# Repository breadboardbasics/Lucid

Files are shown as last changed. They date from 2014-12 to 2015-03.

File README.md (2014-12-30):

This is a repository for my Hackaday project here: http://hackaday.io/project/3715-tacs-lucid-dreaming-device

Thanks for checking out my project!
To make everything easier just click the download zip button on the right side of the main page of this repository. 
Then extract everthing to a folder. Next you should be able to view the board and schematic files with KiCad or
you can just view the schematic with the pdf that I included. 

All code that is used in this project will also be posted in this repository and will be updated as I progress through the 
project. 

Also for those wondering RevA (Revision A) is what I am calling the first version of the hardware. It is still a work in 
progress but is almost complete and ready for testing. 

**Disclaimer** - I am not responsible for any damages or injury related to this project
The project is very safe. It is battery powered and has a maximum of about 18v present on the board. Do not attempt to use 
the headset when it is connected to mains (the wall) in any way ex. you are powereing it with the programmer which is connected 
a desktop computer ect.

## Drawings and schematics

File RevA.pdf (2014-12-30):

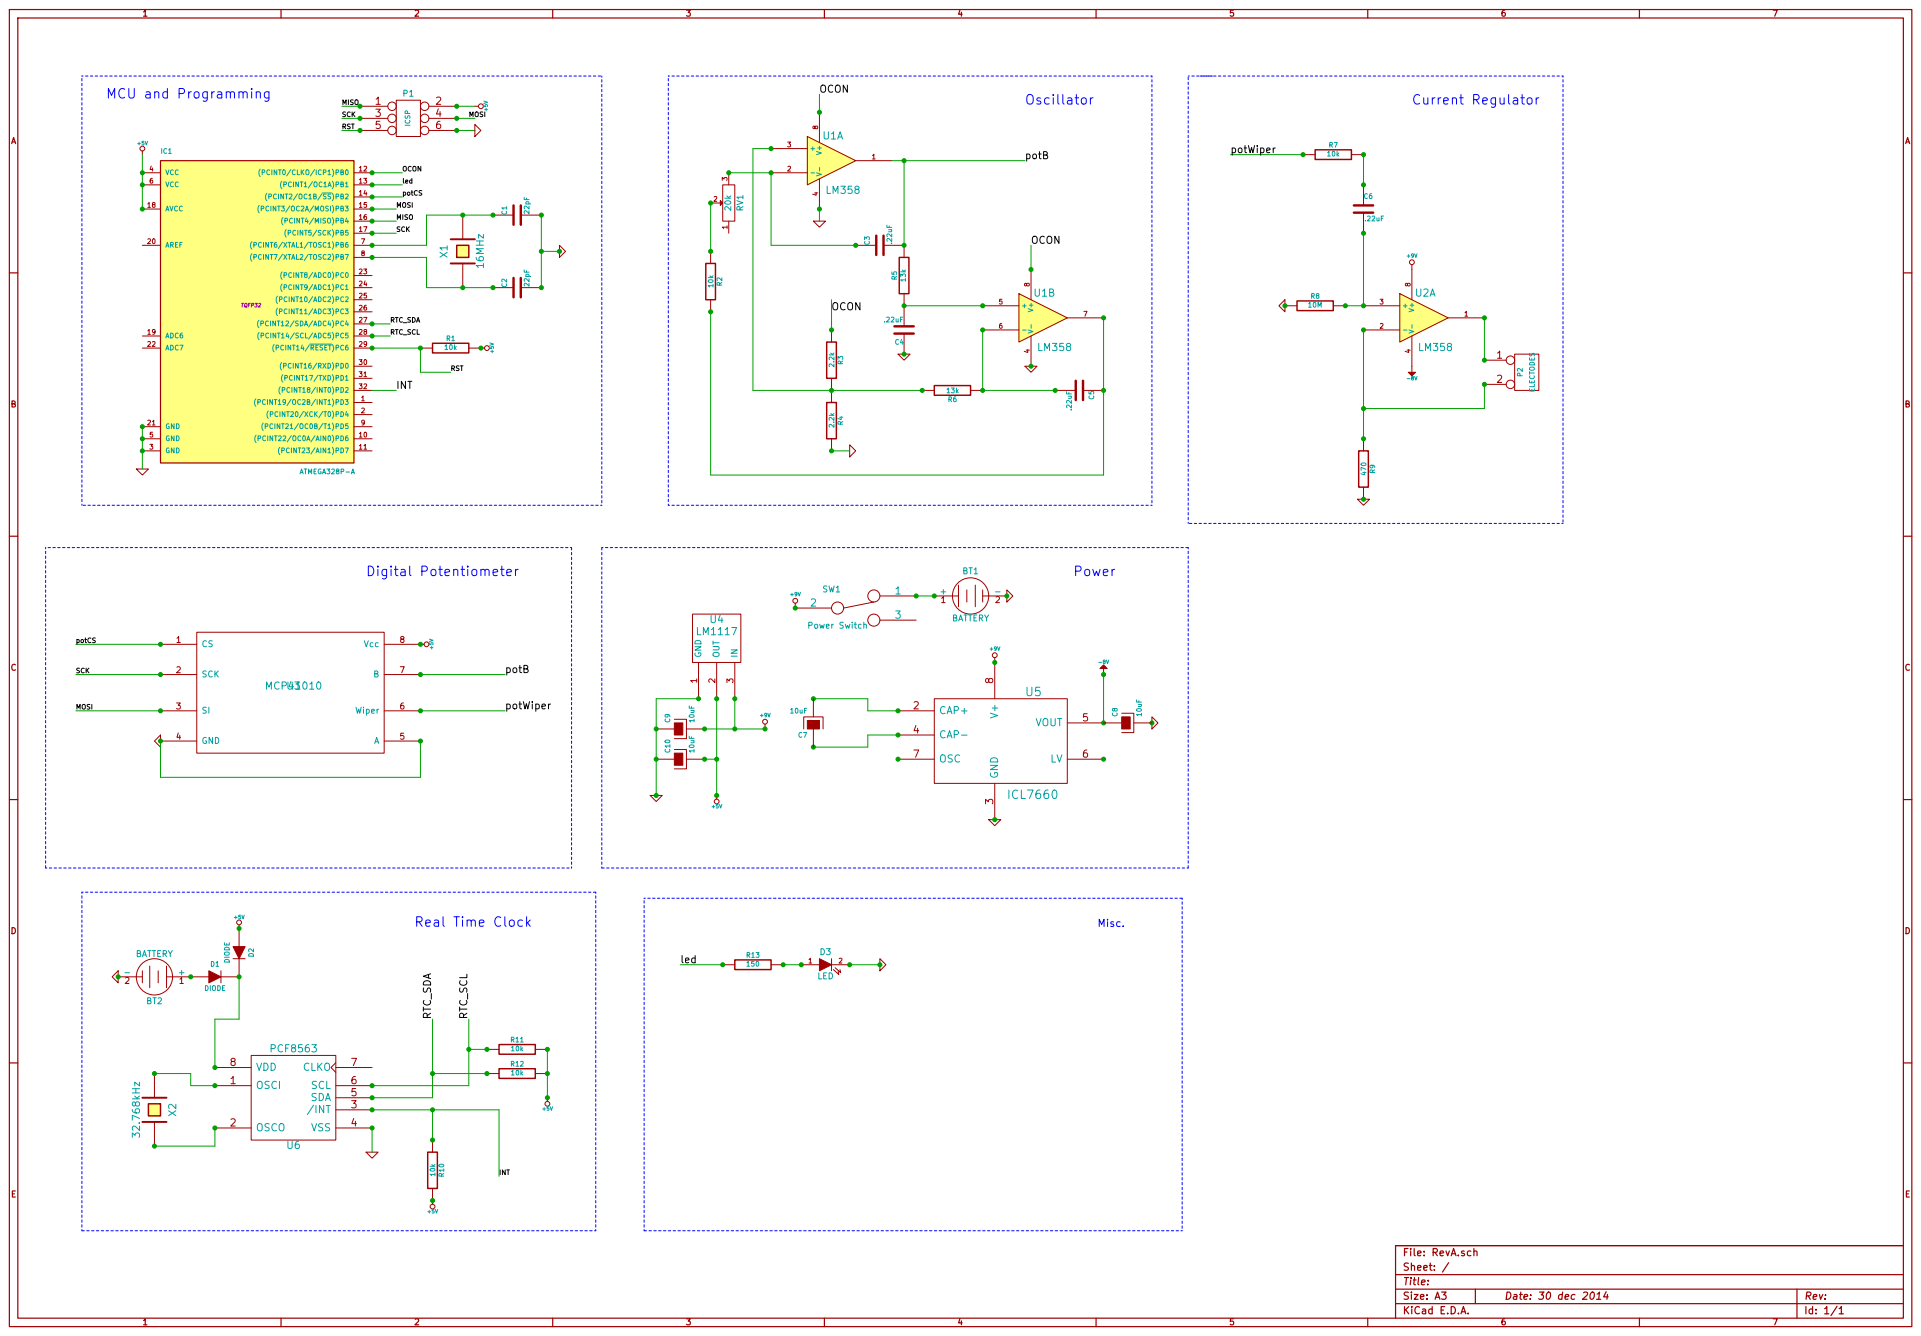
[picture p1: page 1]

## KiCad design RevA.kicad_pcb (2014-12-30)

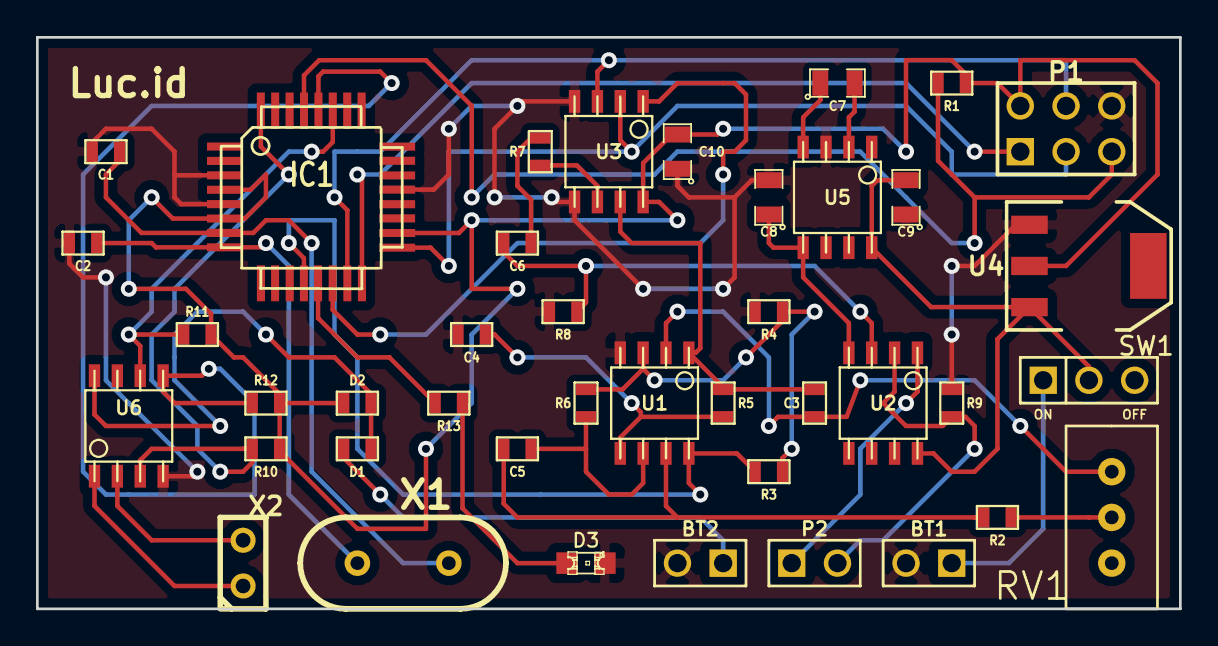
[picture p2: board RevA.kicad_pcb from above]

Board: 2 copper layers, 63.5 x 31.8 mm, 41 parts (0 on the bottom side), 36 nets.

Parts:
BT1, BT2: BATTERY; PIN_ARRAY_2X1
C1, C2: 22pF; SM0603
C3, C4, C5, C6: .22uF; SM0603
C7, C8, C9, C10: 10uF; SM0805
D1, D2: DIODE; SM0603
D3: LED; LED-0805
IC1: ATMEGA328P-A; TQFP32
P1: ICSP; pin_array_3x2
P2: ELECTODES; PIN_ARRAY_2X1
R1, R2, R7, R10, R11, R12: 10k; SM0603
R3, R4: 2.2k; SM0603
R5, R6: 13k; SM0603
R8: 10M; SM0603
R9: 2.5k; SM0603
R13: 3.3k; SM0603
RV1: 20k; TRIMPOT_V
SW1: Power Switch; PIN_ARRAY_3X1
U1, U2: LM358; so-8
U3: MCP41010; so-8
U4: LM1117; SOT223
U5: ICL7660; so-8
U6: PCF8563; so-8
X1: 16MHz; HC-49V
X2: 32.768kHz; C1

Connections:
+5V: C10.2, D2.1, IC1.4, IC1.6, IC1.18, P1.2, R1.2, R10.2, R11.2, R12.2, U3.8, U4.2
+9V: C9.2, SW1.2, U2.8, U4.3, U5.8
-8V: C8.1, U2.4, U5.5
/INT: IC1.32, R10.1, U6.3
/MISO: IC1.16, P1.1
/MOSI: IC1.15, P1.4, U3.3
/OCON: IC1.12, R3.1, U1.8
/RST: IC1.29, P1.5, R1.1
/RTC_SCL: IC1.28, R12.1, U6.5
/RTC_SDA: IC1.27, R11.1, U6.6
/SCK: IC1.17, P1.3, U3.2
/led: IC1.13, R13.1
/potB: C3.2, R5.2, U1.1, U3.7
/potCS: IC1.14, U3.1
/potWiper: R7.1, U3.6
GND: BT1.2, BT2.2, C1.2, C2.2, C4.1, C8.2, C9.1, C10.1, D3.2, IC1.3, IC1.5, IC1.21, P1.6, R4.2, R8.1, R9.2, U1.4, U3.4, U3.5, U4.1, U5.3, U6.4
unnamed: C6.2, R8.2, U2.3
unnamed: C6.1, R7.2
unnamed: D1.2, D2.2, U6.8
unnamed: P2.2, R9.1, U2.2
unnamed: P2.1, U2.1
unnamed: U6.1, X2.1
unnamed: U6.2, X2.2
unnamed: D3.1, R13.2
unnamed: BT1.1, SW1.1
unnamed: C7.1, U5.4
unnamed: C7.2, U5.2
unnamed: C5.1, R2.2, U1.7
unnamed: R2.1, RV1.2
unnamed: R3.2, R4.1, R6.2, U1.3
unnamed: C2.1, IC1.8, X1.1
unnamed: C1.1, IC1.7, X1.2
unnamed: C3.1, RV1.3, U1.2
unnamed: C5.2, R6.1, U1.6
unnamed: C4.2, R5.1, U1.5
unnamed: BT2.1, D1.1

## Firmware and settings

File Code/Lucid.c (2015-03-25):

#define F_CPU 16000000
#include <avr/io.h>
#include <util/delay.h>
#include <avr/interrupt.h>
#include <avr/sleep.h>

#define output_low(port,pin) port &= ~(1<<pin)
#define output_high(port,pin) port |= (1<<pin)
#define set_input(portdir,pin) portdir &= ~(1<<pin)
#define set_output(portdir,pin) portdir |= (1<<pin)
#define AlarmEnable 0x7F

uint8_t buffRX[8];
uint8_t spiErrors;

void SPI_begin();
uint8_t SPI_transfer(uint8_t _data);
void potWrite(uint8_t data);
void readTime();
void writeTime(int secs, int mins, int hours);
void setAlarm(int mins, int hours);
void clearAlarm();
void twiRX(const uint8_t targetAddress, uint8_t numBytes);
void twiTX(uint8_t twiData);
void txStart();
void txStop();
void twintWait();
void enableClocks();
uint8_t decToBcd(int val);
void blink();

volatile int seconds,mins,hours;
volatile int flag = 0;

int hour = //varHour
int min = //varMin
int current = //varCurrent
float pdurr = //varPdurr
float npdurr = //varNpdurr

ISR(INT0_vect){ //Alarm routine, after alarm set flag to 1
	flag = 1;
	}

////////////////////////////////////////////////////////////////////////////////////////////////////////////////////////
int main(){
  enableClocks();
  SPI_begin();
  set_output(DDRB,0); //Set ocon as output
  set_output(DDRB,1); //Set led pin as output
  set_input(DDRD,2); //Set D2 as an input (for interrupt)
  
  int i,t;
  
  const char time[] = __TIME__; //Get current time from PC when compiling
  int myhour = 10*(time[0] - '0') + (time[1] - '0');
  int mymin = 10*(time[3] - '0') + (time[4] - '0');
  int mysec = 10*(time[6] - '0') + (time[7] - '0');
	
  writeTime(mysec, mymin, myhour); //Write current time to RTC
  setAlarm(min, hour);//Set alarm based on input from .bat file
  
  EIMSK |= (1 << INT0); //Turns on INT0
  EICRA = 2; //Set int0 interrupt to trigger on falling edge
  sei(); //Enable interrupts
  
  int steps = (-64 * current / 375) + 255; //Converts given current to steps on pot
  
  blink();//Blink once to indicate start of test pulse
  
  output_high(PORTB,0);//Turn oscillator on
  i = 255;
  while(i >= steps){ //Ramp Up
	  _delay_ms(20);
	  potWrite(i);
	  i--;
  }
    
  _delay_ms(5000); //Sustain for 5s
	
  while(i >= 255){//Ramp Down
	  _delay_ms(20);
	  potWrite(i);
	  i++;
  }
  output_low(PORTB,0);//Turn oscillator off
  
  blink();
  _delay_ms(100);
  blink();

/////////////////////////////////////////////////////////////////////////////////////////////////////////////////////
  while(1){
    if(!flag){
	  sleep_enable();
      set_sleep_mode(SLEEP_MODE_STANDBY);
      sleep_mode();  //go to sleep
      sleep_disable();
	}
	if(flag){
	  cli();//Disable interrupts
	  clearAlarm();
	  output_high(PORTB,0);//Turn oscillator on
	  output_high(PORTB,1);//Turn led on
	  
	   i = 255;
	  while(i >= steps){ //Ramp Up
	    _delay_ms(20);
	    potWrite(i);
	    i--;
	  }
	  
	 t = 0;
     while(t <= (60*pdurr)){
	  _delay_ms(1000);
	  t++;
     }
	  
	  while(i >= 255){//Ramp Down
	    _delay_ms(20);
	    potWrite(i);
	    i++;
      }
	  writeTime(0,0,1);//Reset Time
	  setAlarm(npdurr,99);//Set alarm for given minutes later we dont care about hours
	  sei();//Enable interrupts
	  output_low(PORTB,0);//Turn oscillator off
	  output_low(PORTB,1);//Turn led off
	  //Loop and go back to sleep
  }
  }
////////////////////////////////////////////////////////////////////////////////////////////////////////////////////
  return(0);
}

void potWrite(uint8_t data){
  output_low(PORTB,2);//Set SS low
  SPI_transfer(0x11);
  SPI_transfer(data);
  output_high(PORTB,2);
}

uint8_t SPI_transfer(uint8_t _data) {
  SPDR = _data;
  while (!(SPSR & _BV(SPIF)))
    ;
  return SPDR;
}

void SPI_begin() {

  // Set SS to high so a connected chip will be "deselected" by default
  output_high(PORTB,2);//Set SS high

  // When the SS pin is set as OUTPUT, it can be used as
  // a general purpose output port (it doesn't influence
  // SPI operations)..........
  set_output(DDRB,2); //Set SS as output

  // Warning: if the SS pin ever becomes a LOW INPUT then SPI
  // automatically switches to Slave, so the data direction of
  // the SS pin MUST be kept as OUTPUT.
  SPCR |= _BV(MSTR);
  SPCR |= _BV(SPE);

  set_output(DDRB,5); //Set SCK as output
  set_output(DDRB,3); //Set MOSI as output
}

void writeTime(int secs, int mins, int hours){
  txStart();
  twiTX(0xA2);// Send device write address
  twiTX(0x02);// Set register pointer to seconds
  twiTX(decToBcd(secs));//set seconds
  twiTX(decToBcd(mins));//set mins
  twiTX(decToBcd(hours));//set hours
  twiTX(0x01);//Set days to 1
  twiTX(0x00);//Set weekdays to 0
  twiTX(0x01);//Set Century_months to 1
  twiTX(0x00);//Set years to 0
  txStop();
  }
  
void readTime(){
  txStart();
  twiTX(0xA2);// Send device write adress
  twiTX(0x02);// Send start adress of seconds
  txStop();
  txStart();
  twiRX(0xA3,3);//Read seconds mins hours
  txStop();
  
  seconds = (((buffRX[0] & 0x70)>>4) * 10) + (buffRX[0] & 0x0F);
  mins = (((buffRX[1] & 0x70)>>4) * 10) + (buffRX[1] & 0x0F);
  hours = (((buffRX[2] & 0x30)>>4) * 10) + (buffRX[2] & 0x0F);
  }

void setAlarm(int mins, int hours){
  txStart();
  twiTX(0xA2);// Send device write address
  twiTX(0x09);// Send start address of Minute_alarm
  twiTX(AlarmEnable & decToBcd(mins));
  if(hours != 99){
    twiTX(AlarmEnable & decToBcd(hours));
  }
  else{
	twiTX(0x80); //Disable hour alarm
  }
	
  txStop();
  txStart();
  twiTX(0xA2);// Send device write address
  twiTX(0x01);// Send address of Control Register 2
  twiTX(0x02);// Enable Alarm Interrupt 
  txStop();
  }
  
void clearAlarm(){
  twiTX(0xA2);// Send device write address
  twiTX(0x01);// Send address of Control Register 2
  twiTX(0x00);// Disable Alarm and clear alarm flag
  txStop();  
  flag = 0;
  }
  
void twiRX(const uint8_t targetAddress, uint8_t numBytes){
  if(0 == numBytes){
    return;
  } //Should never want to read one byte
  else if(numBytes > 8)
  {
    numBytes = 8;
  }
  TWDR =  targetAddress; //Select address to access for read
  TWCR = (1<<TWINT)|(1<<TWEN); //Send TWDR
  twintWait();
  int i = 0;
  while(i < numBytes){
    if(i < numBytes - 1) //Check if -not- the last byte to be read
    {
      TWCR = (1<<TWINT)|(1<<TWEN)|(1<<TWEA);
    }
    else //When reading our last byte we should return NACK
    {
      TWCR = (1<<TWINT)|(1<<TWEN); //Return NACK because we're finished reading after this
    }
    //Wait for return byte
    twintWait();
    buffRX[i] = TWDR;
	i++;
  }
}

void twiTX(uint8_t twiData)
{
  TWDR = twiData;
  TWCR = (1<<TWINT)|(1<<TWEN); //Send TWDR
  twintWait(); //Wait for TWDR to finish transmitting 
}

void txStart()
{
  TWCR = (1<<TWINT)|(1<<TWSTA)|(1<<TWEN); //Send START
  twintWait();
}

void txStop()
{
  TWCR = (1<<TWINT)|(1<<TWEN)|(1<<TWSTO); //Transmit STOP
  int z = 0;
  while (!(TWCR | (0<<TWSTO))) //Wait for STOP to finish and TWSTO to be cleared
  {
    z++;
    //Assuming 5 clock cycles per loop, count up to 100mS before just returning
    if(z > 320000)	//F_CPU/10/5
    {
      spiErrors++; //Let 
      return; //Just return, this one time read will be wrong but it shouldn't matter much
    }    
  }
}

void twintWait() //Wait for to finish TWI operation
{
  uint16_t z = 0;
  uint16_t j = 0;
  while(!(TWCR & (1<<TWINT)))
  {
    z++;
    //Assuming 8 clock cycles per loop, count up to 100mS before just returning VERY ROUGH GUESS
    if(j > 2)	//F_CPU/10/8 is the target number of increments for z
    {
      spiErrors++; //Let 
      return; //Just return, this one time read will be wrong but it shouldn't matter much
    }
    if(z > 65000) //z and j are used because one 16-bit integer can't fit the appropriate value
    {
      z = 0;
      j++;
    }
  }
}

void enableClocks()
  {
	  //Use non-standard define names to avoid conflicts
	  #define currentCPUfreq 16000000
	  
	  #define desiredSPIclock 100000
	  // initialize twi prescaler to 1 and set bit rate
	  TWSR &= ~(1 << TWPS0); //Clear TWSP0
	  TWSR &= ~(1 << TWPS1); //Clear TWSP1
	  //At 16MHz TWI can be set from 3486Hz to 1MHz without using the prescaler
	  TWBR =  (currentCPUfreq/desiredSPIclock - 16)/2;
	  /* twi bit rate formula from atmega128 manual pg 204
	  SCL Frequency = CPU Clock Frequency / (16 + (2 * TWBR))
	  note: TWBR should be 10 or higher for master mode
	  We don't want to mess with the prescaler if we can avoid it
	  It is 72 for a 16mhz board with 100kHz TWI */
	}
	
uint8_t decToBcd(int val)
{
    return ( (val/10*16) + (val%10) );
}

void blink(){
	output_high(PORTB,1);//Turn led on
	_delay_ms(200);
	output_low(PORTB,1);//Turn led off
}

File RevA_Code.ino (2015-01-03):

//Version 1.0 - Tyler Sisk - 1/2/15
//Use with arduino, place in folder named RevA_Code, also must have the Rtc_Pcf8563 library (look for it on github) 
//Open in arduino and go to file, upload using programmer
//Make sure that your programmer is selected under tools. 

#include <Wire.h>
#include <Rtc_Pcf8563.h>
#include <SPI.h>
#include <avr/sleep.h>

int led = 9;
const int cs = 10;
int ocon = 8;
Rtc_Pcf8563 rtc;
volatile int alarm_flag=0;

void isr(){ //interrupt service routine
  alarm_flag=1;
}

void setup(){
  pinMode(led,OUTPUT);
  pinMode (cs, OUTPUT);
  pinMode (ocon, OUTPUT);
  pinMode(3, INPUT);
  SPI.begin();
  rtc.initClock();
  delay(1000);
  attachInterrupt(0, isr, FALLING);
  
  digitalWrite(cs,HIGH);
  digitalWrite(ocon,LOW);
  digitalWrite(led,LOW);

  //This part is not yet used but will be in the final version
  //const char time[] = __TIME__; //Get current time from PC when compiling
  //int myhour = 10*(time[0] - '0') + (time[1] - '0');
  //int mymin = 10*(time[3] - '0') + (time[4] - '0');
  //int mysec = 10*(time[6] - '0') + (time[7] - '0');
  
  rtc.setTime(23,22,52);

  //////////////////////////////////set time to wake up///////////////////////////////////////////////
  int wakemin = 23;
  int wakehour = 23;
  rtc.setAlarm(wakemin, wakehour, 99, 99); //min,hour,day,weekday, 99 = no alarm value to be set 
  ////////////////////////////////////////////////////////////////////////////////////////////////////
}

void digitalPotWrite(int value)
{
  digitalWrite(cs, LOW);
  SPI.transfer(0x11);
  SPI.transfer(value);
  digitalWrite(cs, HIGH);
}

void clr_alarm()
{
  detachInterrupt(0);
  rtc.clearAlarm();
  delay(1000);
  alarm_flag=0;
  attachInterrupt(0, isr, FALLING);
}

void loop(){

  if(alarm_flag == 0){
    sleep_enable();
    set_sleep_mode(SLEEP_MODE_STANDBY);
    sleep_mode();  //go to sleep
    sleep_disable();
  }

  if(alarm_flag == 1){
    clr_alarm();
    digitalWrite(ocon,HIGH);
    int i = 255;
    digitalWrite(led,HIGH);

    while(i >= 0){  //Ramp Up approximately 10 seconds
      delay(40);
      digitalPotWrite(i);
      i--;
    }

    delay(120000); //Sustain for 2 minutes

    while(i <= 255){  //Ramp Down approximately 10 seconds
      delay(40);
      digitalPotWrite(i);
      i++;
    }
    digitalWrite(led,LOW);
  }
}	

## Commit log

2014-12-30 Create RevA.sch
    This is the schematic file created in KiCad
    [RevA.sch]
2014-12-30 Board File
    Can only be opened in KiCad
    [RevA.kicad_pcb]
2014-12-30 Updated Schems
    [RevA.sch]
2014-12-30 Library File For schematics
2014-12-30 PDF of the schematics
2014-12-30 PDF of Schematics
2015-01-03 Current code for the device
2015-03-24 SPI now working
2015-03-25 Final code (not working yet)
    [Lucid.c]
